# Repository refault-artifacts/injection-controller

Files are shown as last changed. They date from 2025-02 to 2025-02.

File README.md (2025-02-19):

# DDR5 Injection controller
Hardware design files and firmware for the injection controller PCB that
controls the DDR5 interposer PCB by using a Teensy 4.1 microcontroller. This is
a 2-layer PCB.

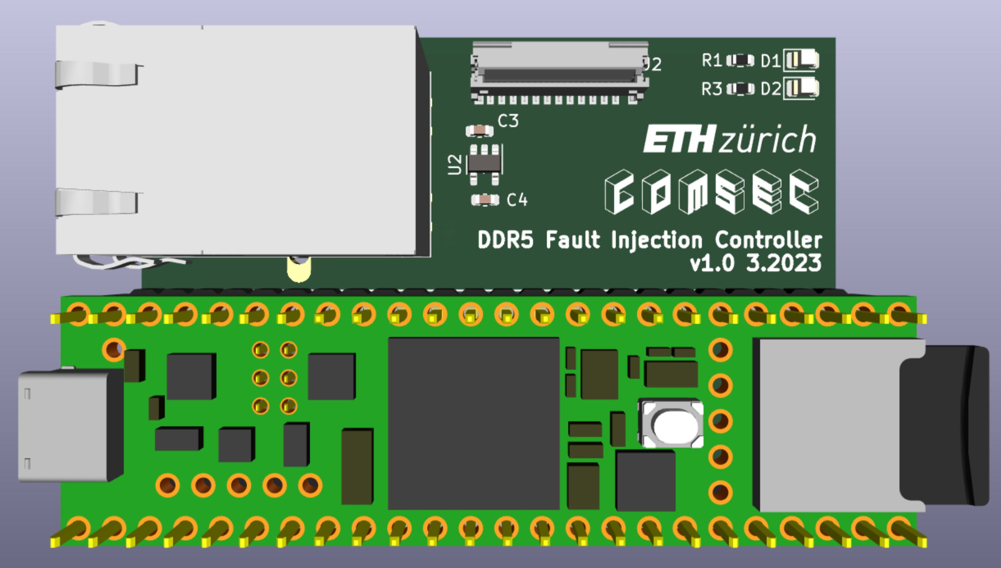
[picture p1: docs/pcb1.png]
3D Rendering of PCB


## Design
The schematic and PCB was designed in KiCAD. Open `hardware/injection-controller.kicad_pro` in KiCAD 8 or later to view the design files.
From there, you should be able to select the schematic and PCB layout.

For convenience, you can also find a PDF version of the schematic in `docs/schematic.pdf`. A bill of materials (BOM) is also provided in `docs`.

### !!! Important !!!
This injection controller was designed for a previous version
of interposer with a different pinout on the flat-flex connector.
This works fine as long as the software is modified accordingly,
but it means that the labels of J2 in the schematic of the injection
controller (e.g., `CA4_LOW`) are not accurate anymore.
Instead, match the pin number of J2 to the appropriate function
of the interposer that you use.
The latest fault injection interposer also requires 3.3 V instead
of 1.1V. Hence, the voltage regulator U2 should be replaced
with a 3.3V type.
To be able to power-cycle the experiment machine, we manually
added a mechanical relay with a driving transistor and flyback diode
to the PCB. Those components are not documented here.

## Features

  - **Ethernet**: RJ45 Jack connected to the Ethernet header pins of the Teensy.
 - **Pluggable Teensy**: The Teensy microcontroller board is meant to be
 attached to the PCB by using headers, allowing for easy replacement and
 swapping of microcontroller.
 - **Status LED**: One power LED and one user controllable LED on the board.
- **Flat flex connector**: By using a suitable flat flex cable, the controller
 can be easily connected to the DDR5 fault injector interposer.

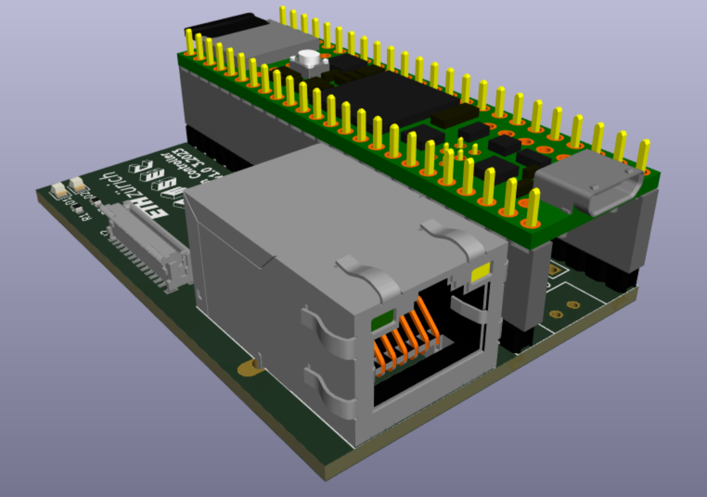
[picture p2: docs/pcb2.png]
Side view of PCB


## Manufacturing
The PCBs were manufactured by JLCPCB and were assembled by hand.
It is reasonable to also order a SMT stencil so soldering is easier.
The Gerber files needed for manufacturing are located at hardware/output.

### Manufactoring options
| Option  | Value |
|---|---|
| Layers  | 2 |
| Dimension | 60.96 mm* 40 mm |
| Product Type | Industrial/Consumer electronics |
| Different Design | 1|
| Delivery Format | Single PCB|
| PCB Thickness | 1.6|
| Impedance Control | no|
| Layer Sequence ||
| PCB Color | Green|
| Silkscreen | White|
| Via Covering | Tented|
| Surface Finish | LeadFree HASL|
| Deburring/Edge rounding | No|
| Outer Copper Weight | 1|
| Gold Fingers | No|
| Flying Probe Test | Fully Test|
| Castellated Holes | no|
| Remove Order Number | No|
| 4-Wire Kelvin Test | No|
| Material Type | FR4-Standard TG 135-140|
| Paper between PCBs | No|
| Appearance Quality | IPC Class 2 Standard|
| Confirm Production file | No|
| Silkscreen Technology | Ink-jet/Screen Printing Silkscreen|
| Package Box | With JLCPCB logo |

## Assembly
Assembly can be done manually using a stencil (ordered with the PCB),
some solder paste and a hot air gun.
### Bill of Materials (BOM)
See docs/bom

## License
Some parts of the PCB may be subject to copyright of third parties 
(e.g. 3D models provided by manufacturer).
Otherwise, the design is released under MIT License.

The KiCad symbol and footprint libraries for the Teensy microcontroller 
are taken from [here](https://github.com/XenGi/teensy_library) 
and [here](https://github.com/XenGi/teensy.pretty), respectively (MIT License).

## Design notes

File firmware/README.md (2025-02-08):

# Injection Controller Firmware

## Build
The project uses code and compilers from the Arduino project 
(files came with the Arduino IDE download). 
It is necessary to install the Arduino IDE and to adapt the paths in
the makefile (default is $HOME/.arduino) in order to build this firmware.

All the files were copied to this repo, only the compilers and upload
utilities are needed from the Arduino IDE. 
It is theoretically possible to use your system's
arm-none-eabi toolchain and Teensy-loader utilities without having to install 
the IDE. This is untested, however.

To initiate the build process, run
``` make ``

This will build and upload the firmware to the Teensy.

## IDs/IP Addresses
The IDs and IPv4 addressed used to differentiate different injection
controllers are hard-coded. Adapt `src/http.cpp` accordingly before
flashing your injection controllers.

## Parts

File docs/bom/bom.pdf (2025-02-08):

Sheet1

Page 1

# Bill of Materials (BOM)

Project: | stgloor-injection-controller
Date: | 07.03.23
No | Qty Reference | Value | Footprint | Manufacturer | Manufacturer Part No. | Supplier Supplier Part No. | Comment
1 | 1 | U1 | | Teensy:Teensy41 | PJRC | TEENSY41 | PJRC | TEENSY41
2 | 1 | U2 | | Package_TO_SOT_SMD:SOT-23-5 | Texas Instruments | TLV73311PQDBVRQ1 | Digikey | 296-TLV73311PQDBVRQ1TR-ND
3 | 2 | D1,D2 | Green | LED_SMD:LED_0805_2012Metric | Kingbright | APHCM2012CGCK-F01 | Digikey | 754-1094-2-ND
4 | 2 | R1,R2 | 120 | Resistor_SMD:R_0603_1608Metric | Bourns Inc. | CR0603-FX-1200ELF | Digikey | CR0603-FX-1200ELFTR-ND
5 | 1 | R3 | 330 | Resistor_SMD:R_0603_1608Metric | Bourns Inc. | CR0603-JW-331ELF | Digikey | CR0603-JW-331ELFTR-ND
6 | 5 | C1-C5 | 100n | Capacitor_SMD:C_0603_1608Metric | Samsung Electro-Mechanics | CL10B104KB8NNWC | Digikey | 1276-1935-2-ND
7 | 1 | J2 | | ddr5:5019512430 | Molex | 501951-2430 | Mouser | 538-501951-2430
8 | 1 | J1 | | DDR5:480251090 | Molex | 480251090 | Digikey | WM5483-ND

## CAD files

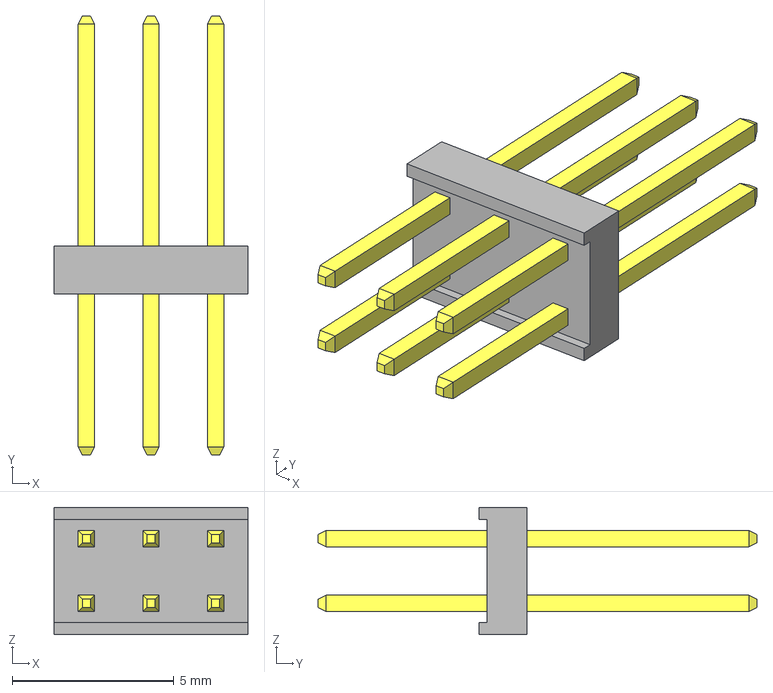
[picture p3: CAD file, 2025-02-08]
hardware/step/MTMM-103-09-G-D-280.stp
6.00 x 13.6 x 3.94 mm
MTMM-103-09-G-D-280_body
MTMM-103-09-G-D-280_pins

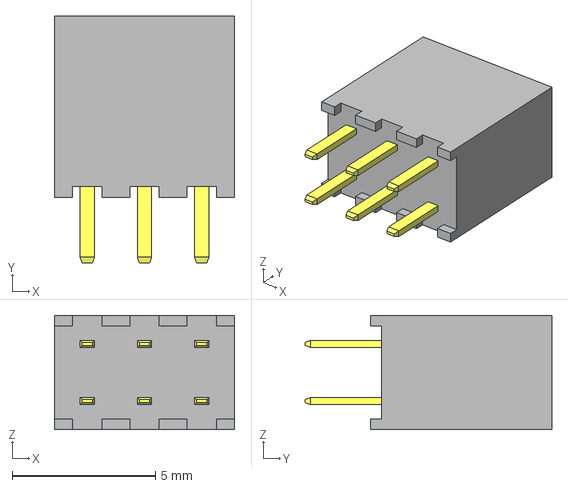
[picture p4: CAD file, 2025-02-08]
hardware/step/SQW-103-01-F-D.stp
6.30 x 8.64 x 4.00 mm
P1SQW-103-01-F-D
S1SQW-103-01-F-D

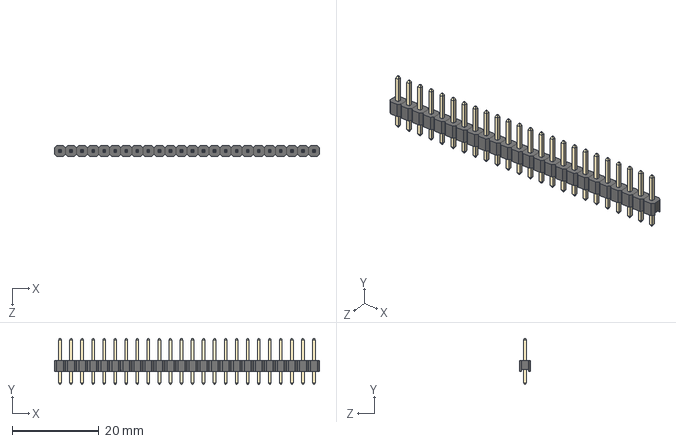
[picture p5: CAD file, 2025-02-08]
hardware/step/PRPC024SAAN-RC.STEP
61.0 x 10.7 x 2.54 mm
1 row end bumps format x 24

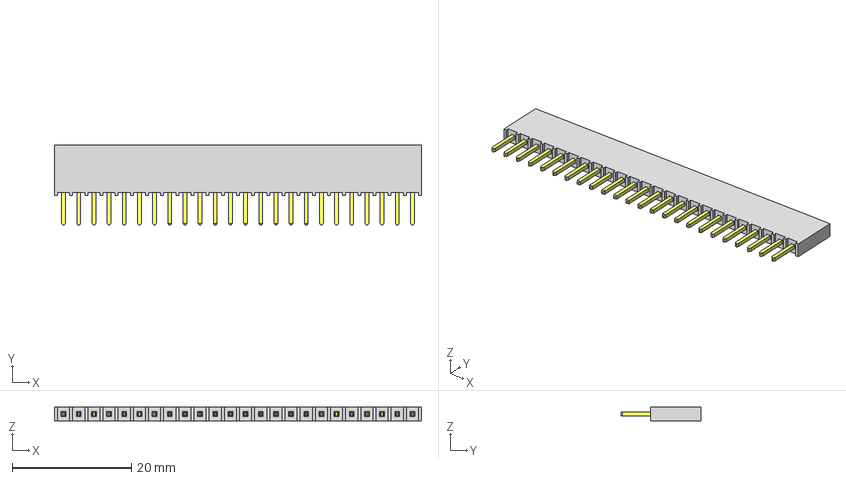
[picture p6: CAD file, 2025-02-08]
hardware/step/SSQ-124-02-G-S.stp
61.5 x 13.4 x 2.41 mm
P2SSQ-124-02-G-S
T1SSQ-124-02-G-S

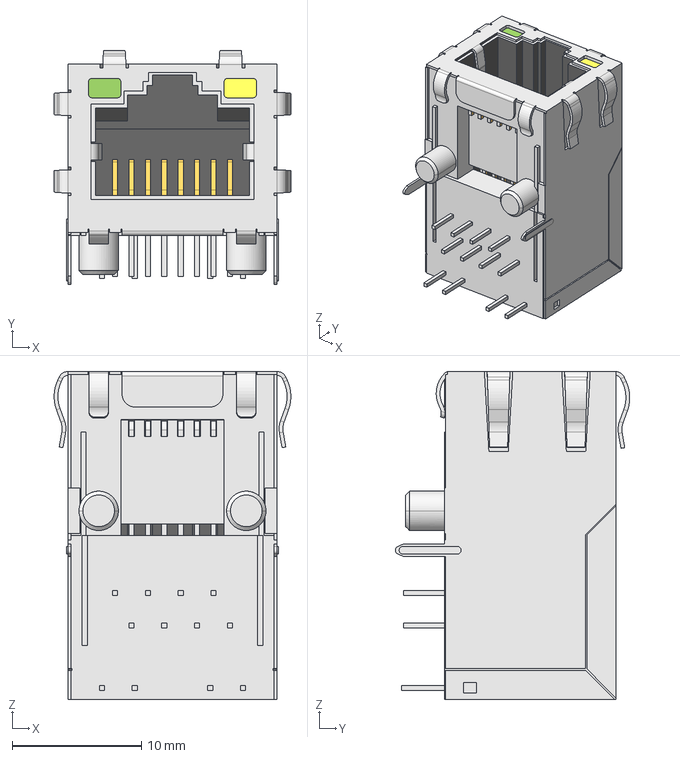
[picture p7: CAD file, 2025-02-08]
hardware/step/480251090.stp
18.3 x 18.2 x 25.4 mm

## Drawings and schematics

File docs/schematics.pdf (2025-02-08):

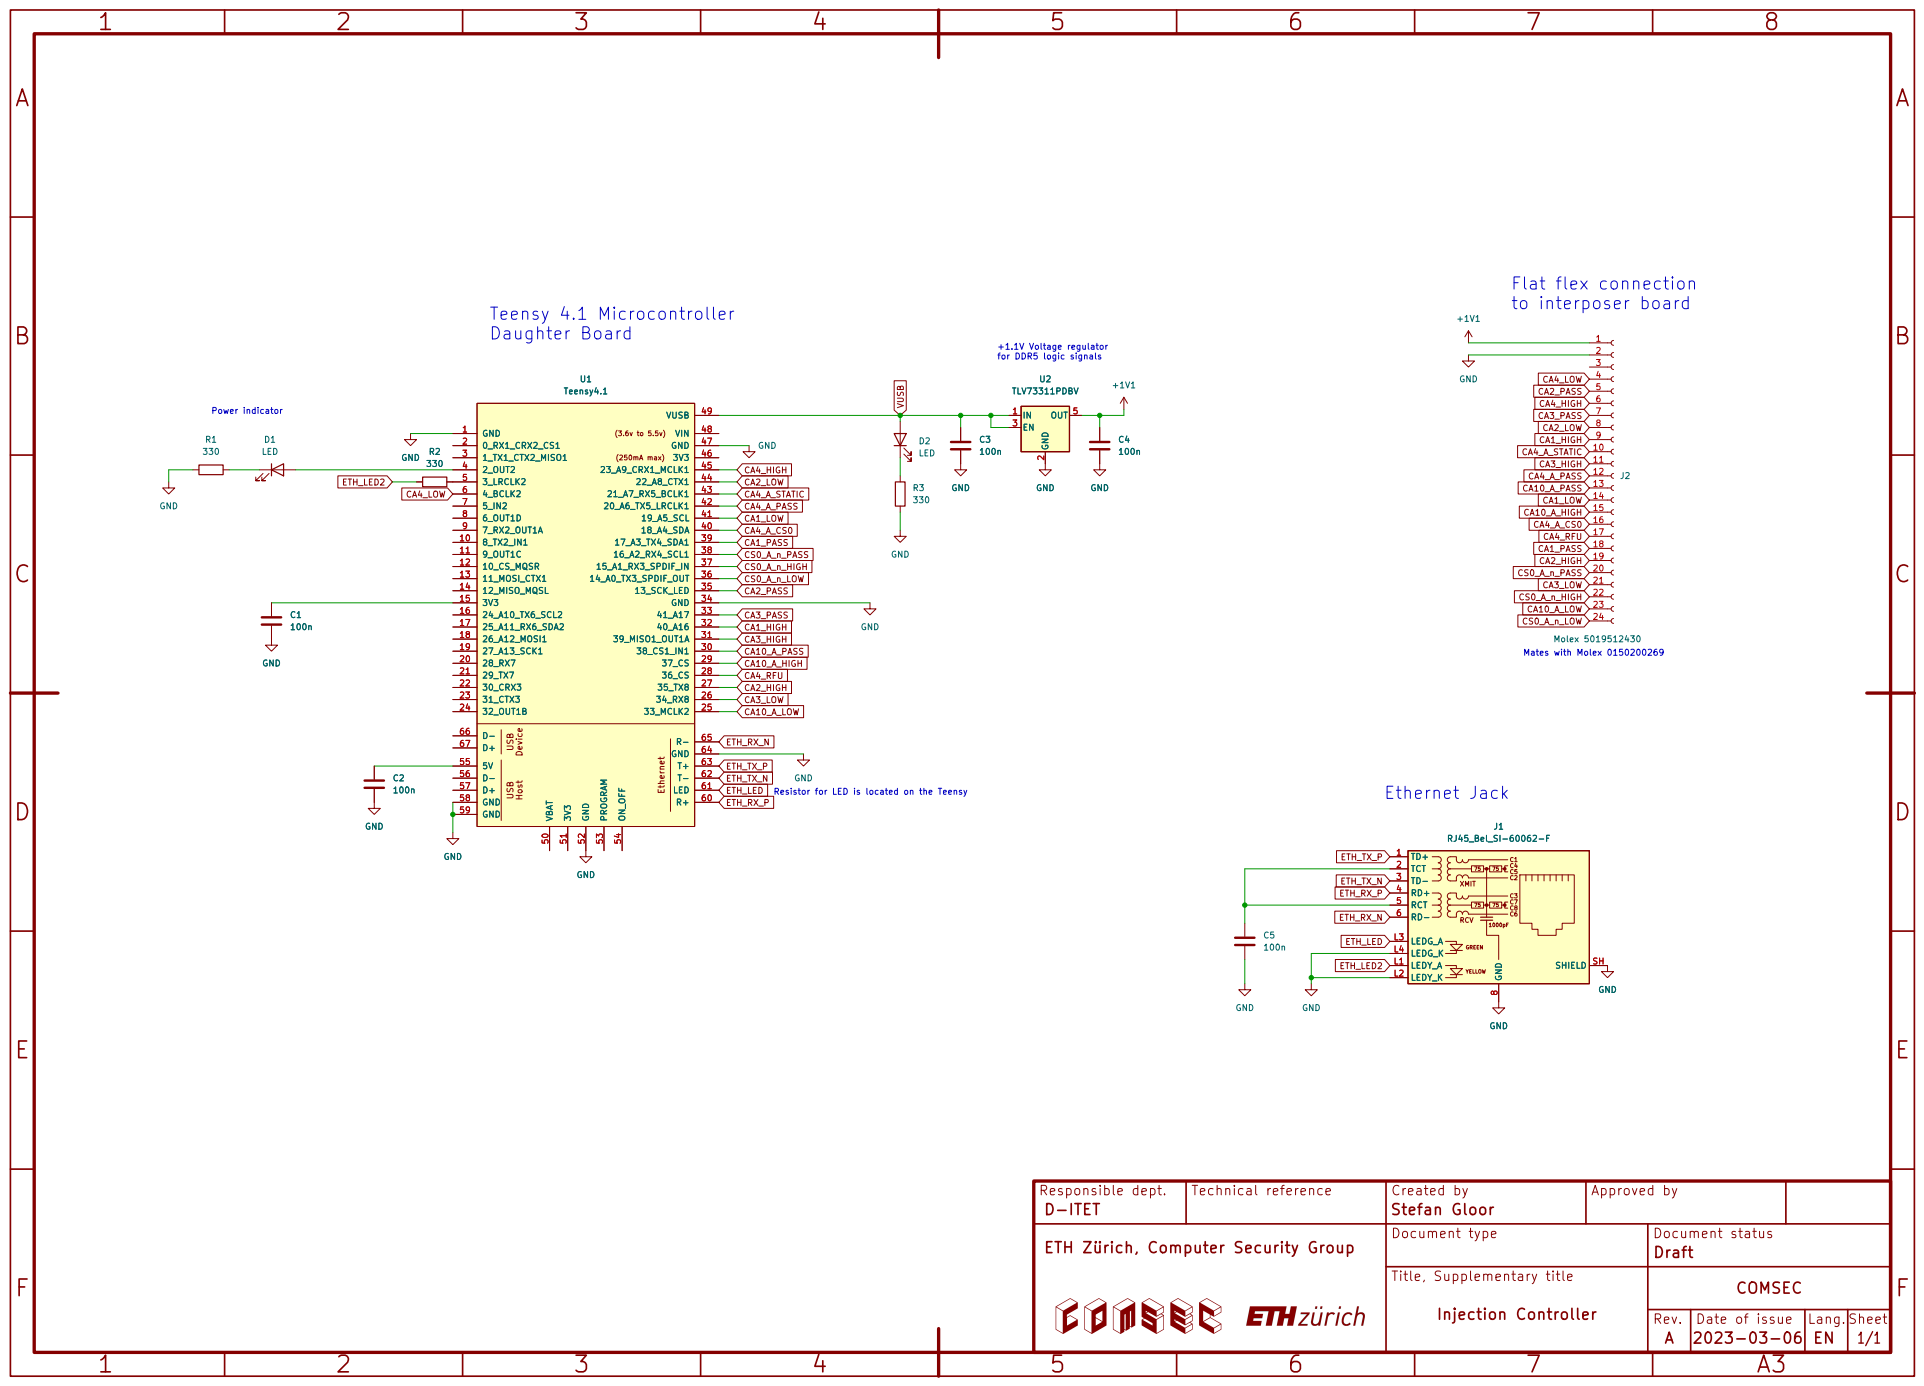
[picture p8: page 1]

2 EN 3 OUT 5 U2 TLV73311PDBV GND GND

2 EN 3 OUT 5 GND GND

þÿETH Zürich, Computer Security Group | | Draft

Title, Supplementary title | COMSEC

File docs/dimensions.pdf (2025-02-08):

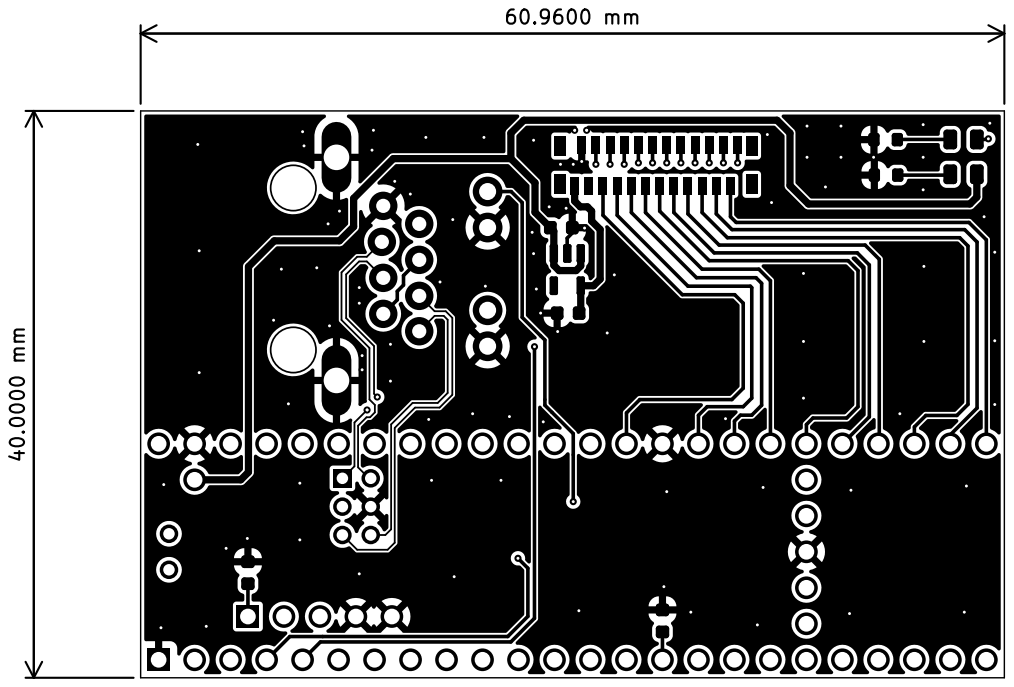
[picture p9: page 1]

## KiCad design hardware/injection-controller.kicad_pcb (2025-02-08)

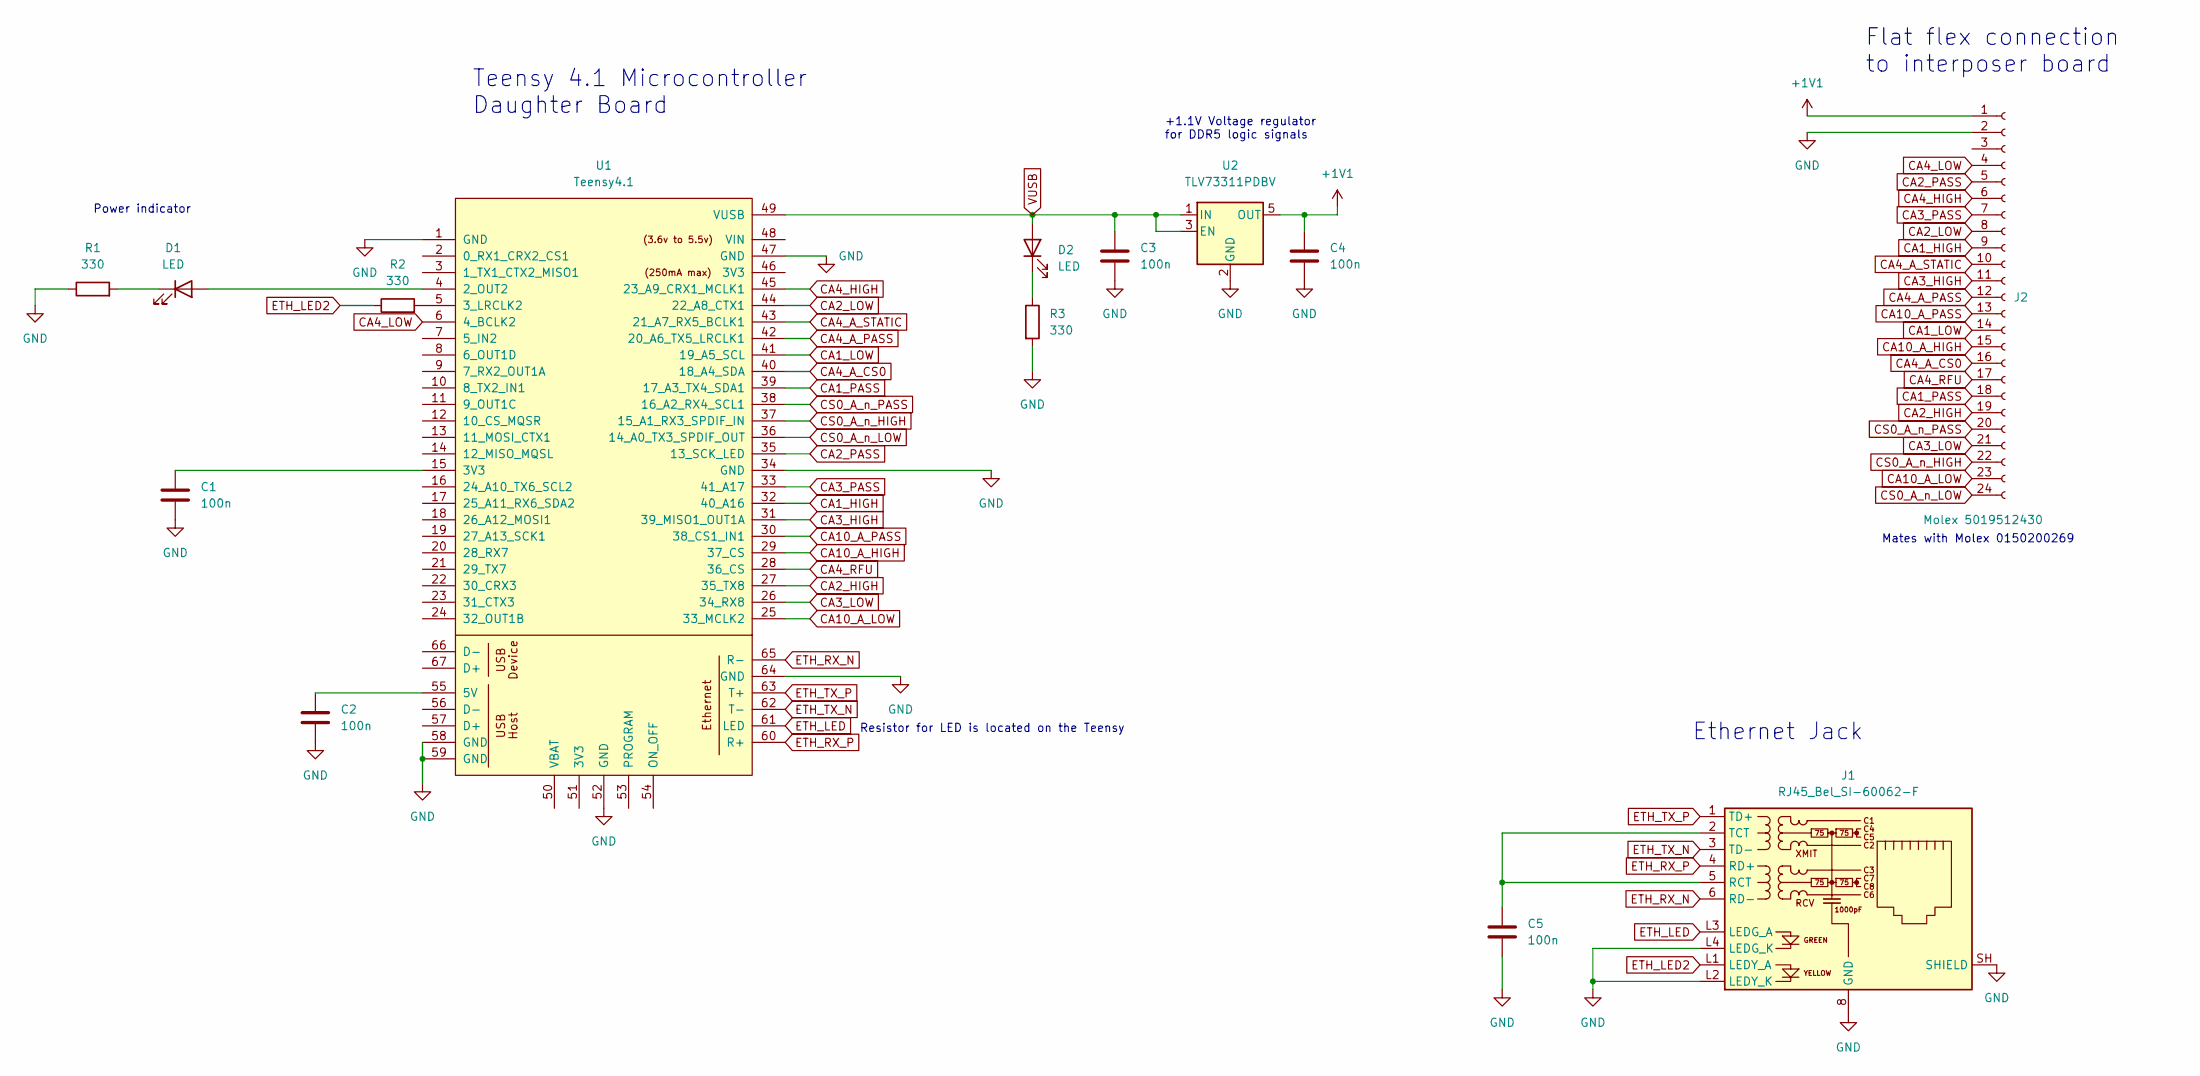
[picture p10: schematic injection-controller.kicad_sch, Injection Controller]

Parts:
C1, C2, C3, C4, C5: 100n; C_0603_1608Metric
D1, D2: LED; LED_0805_2012Metric
J1: RJ45_Bel_SI-60062-F; 480251090
J2: Molex 5019512430; 5019512430
R1, R2, R3: 330; R_0603_1608Metric
U1: Teensy4.1; Teensy41
U2: TLV73311PDBV; SOT-23-5

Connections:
+1V1: C4.1, J2.1, U2.5 (OUT)
CA1_HIGH: J2.9, U1.32 (40_A16)
CA1_LOW: J2.14, U1.41 (19_A5_SCL)
CA1_PASS: J2.18, U1.39 (17_A3_TX4_SDA1)
CA2_HIGH: J2.19, U1.27 (35_TX8)
CA2_LOW: J2.8, U1.44 (22_A8_CTX1)
CA2_PASS: J2.5, U1.35 (13_SCK_LED)
CA3_HIGH: J2.11, U1.31 (39_MISO1_OUT1A)
CA3_LOW: J2.21, U1.26 (34_RX8)
CA3_PASS: J2.7, U1.33 (41_A17)
CA4_A_CS0: J2.16, U1.40 (18_A4_SDA)
CA4_A_PASS: J2.12, U1.42 (20_A6_TX5_LRCLK1)
CA4_A_STATIC: J2.10, U1.43 (21_A7_RX5_BCLK1)
CA4_HIGH: J2.6, U1.45 (23_A9_CRX1_MCLK1)
CA4_LOW: J2.4, U1.6 (4_BCLK2)
CA4_RFU: J2.17, U1.28 (36_CS)
CA10_A_HIGH: J2.15, U1.29 (37_CS)
CA10_A_LOW: J2.23, U1.25 (33_MCLK2)
CA10_A_PASS: J2.13, U1.30 (38_CS1_IN1)
CS0_A_n_HIGH: J2.22, U1.37 (15_A1_RX3_SPDIF_IN)
CS0_A_n_LOW: J2.24, U1.36 (14_A0_TX3_SPDIF_OUT)
CS0_A_n_PASS: J2.20, U1.38 (16_A2_RX4_SCL1)
ETH_LED: J1.L3 (LEDG_A), U1.61 (LED)
ETH_LED2: J1.L1 (LEDY_A), R2.1
ETH_RX_N: J1.6 (RD-), U1.65 (R-)
ETH_RX_P: J1.4 (RD+), U1.60 (R+)
ETH_TX_N: J1.3 (TD-), U1.62 (T-)
ETH_TX_P: J1.1 (TD+), U1.63 (T+)
GND: C1.2, C2.2, C3.2, C4.2, C5.2, J1.8 (GND), J1.L2 (LEDY_K), J1.L4 (LEDG_K), J1.SH (SHIELD), J2.2, R1.1, R3.2, U1.1 (GND), U1.34 (GND), U1.47 (GND), U1.52 (GND), U1.58 (GND), U1.59 (GND), U1.64 (GND), U2.2 (GND)
unnamed: C1.1, U1.15 (3V3)
unnamed: C2.1, U1.55 (5V)
unnamed: C5.1, J1.2 (TCT), J1.5 (RCT)
unnamed: D1.1 (K), R1.2
unnamed: D1.2 (A), U1.4 (2_OUT2)
unnamed: D2.1 (K), R3.1
unnamed: R2.2, U1.5 (3_LRCLK2)
VUSB: C3.1, D2.2 (A), U1.49 (VUSB), U2.1 (IN), U2.3 (EN)

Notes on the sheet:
Mates with Molex 0150200269
+1.1V Voltage regulator for DDR5 logic signals
Flat flex connection to interposer board
Power indicator
Resistor for LED is located on the Teensy
Ethernet Jack
Teensy 4.1 Microcontroller Daughter Board

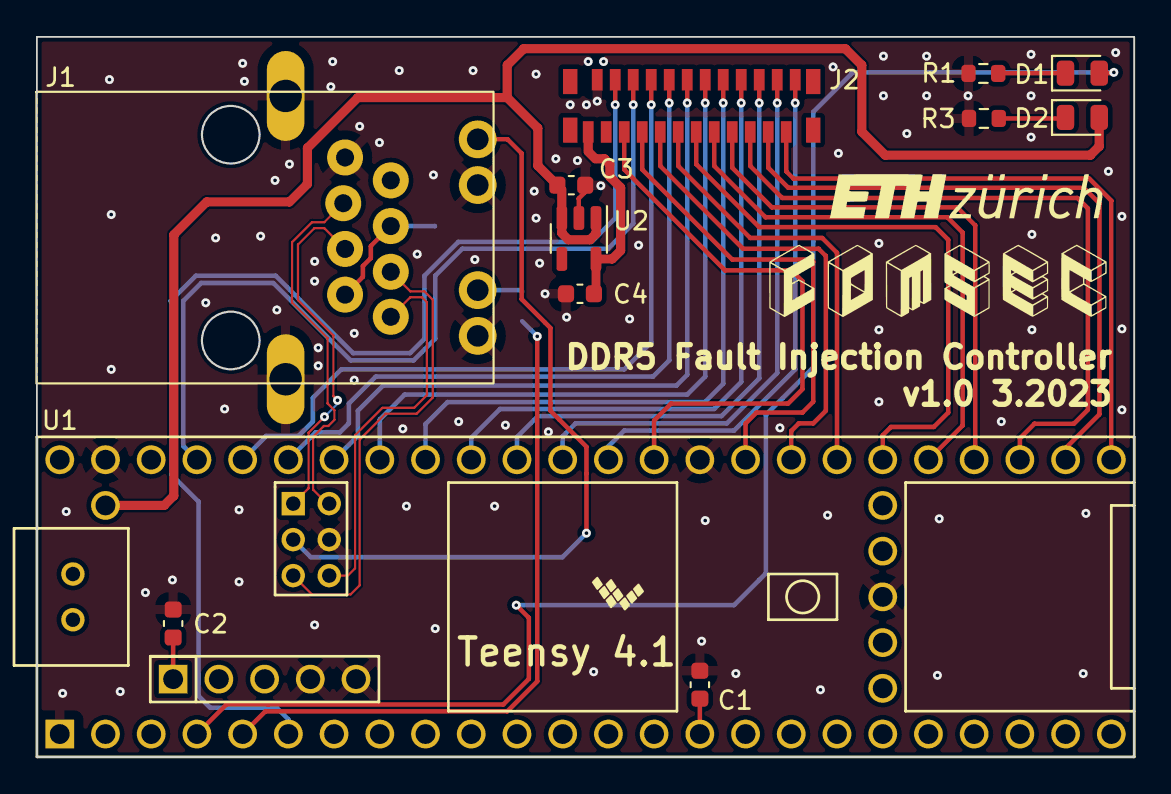
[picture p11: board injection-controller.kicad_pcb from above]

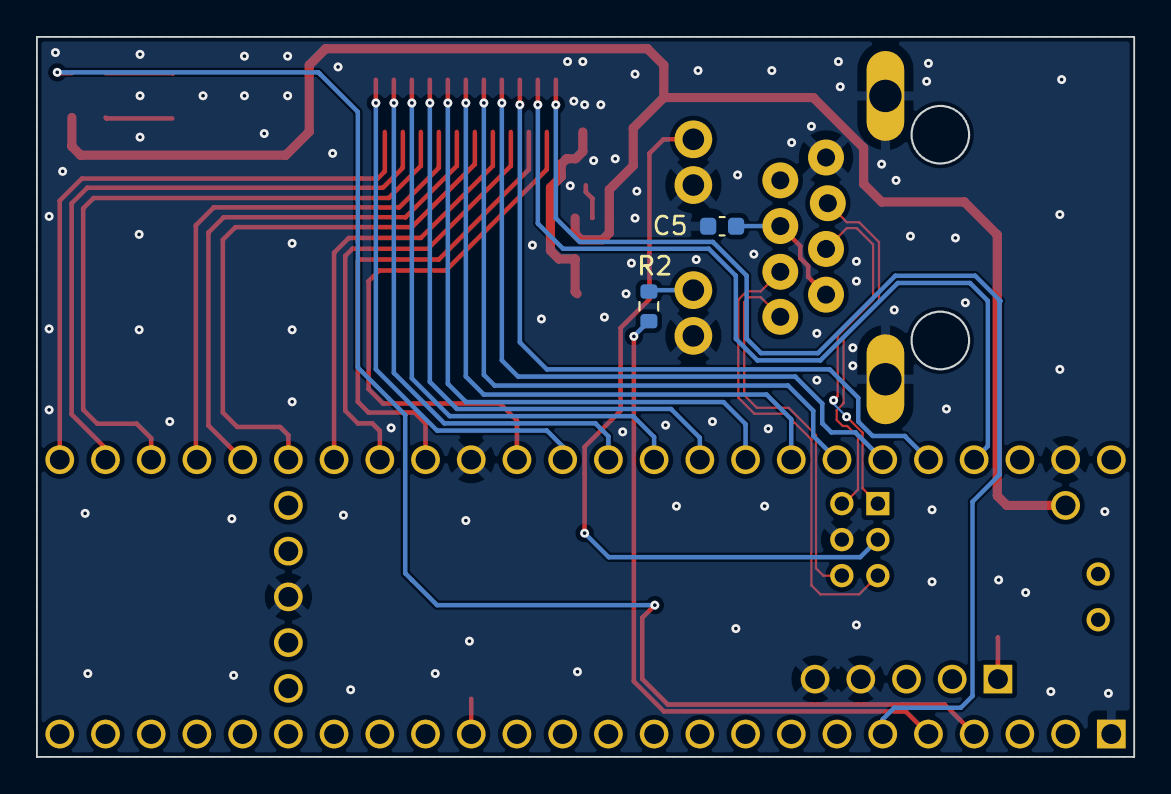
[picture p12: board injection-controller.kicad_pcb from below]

Board: 2 copper layers, 61.0 x 40.0 mm, 14 parts (2 on the bottom side), 37 nets.

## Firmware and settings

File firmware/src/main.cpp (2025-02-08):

#include <Arduino.h>
#include <NativeEthernet.h>
#include <TeensyThreads.h>
#include <SPI.h>

#include "pins.h"
#include "helper.h"
#include "http.h"
#include "fi.h"

/* Button press times */
#define PWR_BTN_LONG_PRESS 5000
#define PWR_BTN_SHORT_PRESS 1000

/* Seconds after machine is presumed dead after silence */
#define ALIVE_TIMEOUT 10

const char *state_names[] = {
	"Unknown",
	"Alive",
	"Crashed",
};
volatile enum state_t state = STATE_UNKNOWN;

/* Flags which indicate whether the power button should be pressed */
volatile bool pwr_btn_short_pressed = false;
volatile bool pwr_btn_long_pressed = false;

/* This counter increments continously each second.
 * If the experiment machine is alive, it will send a 
 * heart beat packet via USB HID, resetting this counter.
 * If this counter exceeds ALIVE_TIMEOUT, the machine
 * is believed to have crashed.
 */
uint32_t alive_tick_cnt = 0;

/* This thread checks for the btn_flags which 
 * indicates that the power button should be pressed 
 * and actives the power button relay for some time 
 */
void power_button()
{
	while (1) {
		if (pwr_btn_long_pressed || pwr_btn_short_pressed) {
			digitalWriteFast(PIN_PWR_BTN, HIGH);
			threads.delay(pwr_btn_long_pressed ?
					      PWR_BTN_LONG_PRESS :
					      PWR_BTN_SHORT_PRESS);
			pwr_btn_long_pressed = false;
			pwr_btn_short_pressed = false;
		}
		digitalWriteFast(PIN_PWR_BTN, LOW);
		threads.delay(100);
	}
}

/* This threads checks whether the alive counter
 * has been reset recently (machine is still awake)
 * and sets internal state accordingly.
 * While the machine has not crashed,
 * the LED is blinking.
 */
void alive_tick()
{
	while (1) {
		if (alive_tick_cnt > ALIVE_TIMEOUT) {
			if (state == STATE_ALIVE)
				state = STATE_CRASH;
		} else {
			if (state == STATE_CRASH)
				state = STATE_ALIVE;
			alive_tick_cnt++;
			digitalWrite(PIN_LED_STATUS, LOW);
		}
		threads.delay(500);
		digitalWrite(PIN_LED_STATUS, HIGH);
		threads.delay(500);
	}
}

extern "C" int main()
{
	init_gpios();
	init_http();

	digitalWrite(PIN_LED_ETH_RIGHT, HIGH);

	/* Set time slice of the scheduler to 
     * 1 microseconds. This creates a somewhat
     * large overhead as context switches are expensive.
     * However, it ensures low latency for the fault injection
     */
	threads.setSliceMicros(20);

	/* Start the HTTP and USB server */
	threads.addThread(alive_tick);
	threads.addThread(usb_server);
	threads.addThread(power_button);

	/* If everything is working normally, the user LED
     * on the injection controller should blink
     */

	/* HTTP server does not terminate */
	http_server();

	//usb_server();

	yield();
	return 0;
}

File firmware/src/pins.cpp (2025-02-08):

#include <Arduino.h>
#include "pins.h"

//pin2state[<Teensy pin of a DISC signal>] gives you teensy pin of
//corresponding STATIC signal
uint8_t pin2state[] = {
	// Conversion table for teensy pins
	// of DISC and STATIC signals
	//STATIC DISC
	0, //0
	0, //1
	0, //2
	0, //3
	16, //4
	13, //5
	0, //6
	0, //7
	0, //8
	0, //9
	0, //10
	0, //11
	0, //12
	0, //13
	0, //14
	0, //15
	0, //16
	20, //17
	21, //18
	15, //19
	0, //20
	0, //21
	34, //22
	39, //23
	0, //24
	0, //25
	0, //26
	0, //27
	0, //28
	0, //29
	0, //30
	0, //31
	0, //32
	0, //33
	0, //34
	0, //35
	35, //36
	38, //37
	0, //38
	0, //39
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
};

int init_gpios()
{
	pinMode(PIN_LED_ETH_RIGHT, OUTPUT);
	pinMode(PIN_LED_STATUS, OUTPUT);
	pinMode(PIN_PWR_BTN, OUTPUT);

	/* All fault injection pins */
	pinMode(4, OUTPUT);
	pinMode(5, OUTPUT);
	pinMode(23, OUTPUT);
	pinMode(22, OUTPUT);
	pinMode(21, OUTPUT);
	pinMode(20, OUTPUT);
	pinMode(19, OUTPUT);
	pinMode(18, OUTPUT);
	pinMode(17, OUTPUT);
	pinMode(16, OUTPUT);
	pinMode(15, OUTPUT);
	pinMode(14, OUTPUT);
	pinMode(13, OUTPUT);
	pinMode(41, OUTPUT);
	pinMode(40, OUTPUT);
	pinMode(39, OUTPUT);
	pinMode(38, OUTPUT);
	pinMode(37, OUTPUT);
	pinMode(36, OUTPUT);
	pinMode(35, OUTPUT);
	pinMode(34, OUTPUT);
	pinMode(33, OUTPUT);

	/* HIGH means "passthrough" mode */
	digitalWrite(4, HIGH);
	digitalWrite(5, HIGH);
	digitalWrite(23, HIGH);
	digitalWrite(22, HIGH);
	digitalWrite(21, HIGH);
	digitalWrite(20, HIGH);
	digitalWrite(19, HIGH);
	digitalWrite(18, HIGH);
	digitalWrite(17, HIGH);
	digitalWrite(16, HIGH);
	digitalWrite(15, HIGH);
	digitalWrite(14, HIGH);
	digitalWrite(13, HIGH);
	digitalWrite(41, HIGH);
	digitalWrite(40, HIGH);
	digitalWrite(39, HIGH);
	digitalWrite(38, HIGH);
	digitalWrite(37, HIGH);
	digitalWrite(36, HIGH);
	digitalWrite(35, HIGH);
	digitalWrite(34, HIGH);
	digitalWrite(33, HIGH);

	digitalWrite(PIN_LED_ETH_RIGHT, LOW);
	digitalWrite(PIN_LED_STATUS, LOW);

	return 0;
}

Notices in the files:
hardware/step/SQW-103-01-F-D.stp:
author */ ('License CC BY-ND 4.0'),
